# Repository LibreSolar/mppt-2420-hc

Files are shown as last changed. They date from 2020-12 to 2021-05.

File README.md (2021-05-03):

# MPPT charge controller with HS load switch and CAN

 Prototype built and tested, development ongoing (some issues might still be open).

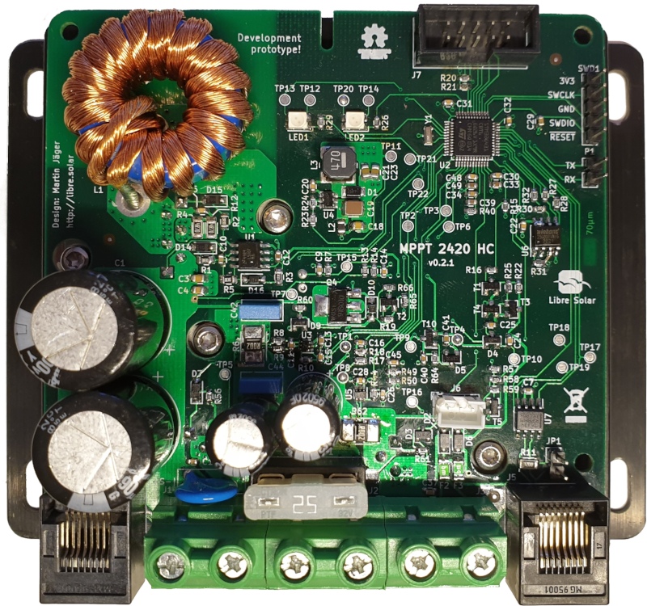
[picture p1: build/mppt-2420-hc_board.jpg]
MPPT 2420 HC


Schematic: [PDF file](build/mppt-2420-hc_schematic.pdf)

Bill of Materials: [CSV file](build/mppt-2420-hc_bom_(hv_supply,can).csv) or [interactive HTML BOM](https://libre.solar/mppt-2420-hc/build/mppt-2420-hc_ibom.html)

Firmware repository: [LibreSolar/charge-controller-firmware](https://github.com/LibreSolar/charge-controller-firmware)

This charge controller design is the replacement for the MPPT 2420 LC. We are also working on an integration of MPPT control algorithms for wind turbines.

## Features

- Solar input terminal
    - Max. 80V (100V MOSFETs used)
    - DC/DC converter inductor current max. 20A
- Battery output terminal
    - 10 V - 32 V (supporting 12 V and 24 V battery systems)
    - Max. current: 20A (limited by inductor current)
- Load terminal: 20A
- New STM32G431 ARM MCU with advanced digital power conversion features
- Expandable via Olimex Universal Extension Connector (UEXT)
- Two bi-color (red/green) LEDs for status indication. Additional user interface can be included in separate PCB in front panel housing and connected via UEXT
- CAN interface via RJ45 connectors

## Mechanical design

- TO-220 MOSFETs can be screwed to large heat sink at the back
- Plastic cover under development

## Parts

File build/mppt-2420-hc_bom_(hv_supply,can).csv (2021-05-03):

Component | References | Value | Footprint | Description | Quantity Per PCB | Manufacturer | PartNumber | Remarks | Config
1 | C11 C15 | 1nF | C_0603_1608 | Unpolarized capacitor | 2 | any
2 | C6 | 2.2nF | C_0603_1608 | Unpolarized capacitor | 1 | any |  | 100V, C0G
3 | C8 C14 C16 C17 C25 C26 C34 C37 C45 | 10nF | C_0603_1608 | Unpolarized capacitor | 9 | any |  | 100V, X7R
4 | C7 C9 C10 C13 C20 C22 C24 C28 C29 C30 C31 C32 C48 | 100nF | C_0603_1608 | Unpolarized capacitor | 13 | any |  |  | +can
5 | C4 | 100nF | C_0805_2012 | Unpolarized capacitor | 1 | any |  | 100V, X7S
6 | C3 C18 | 1µF | C_0805_2012 | Unpolarized capacitor | 2 | any |  | 100V, X7S
7 | C40 | 1µF | C_0603_1608 | Unpolarized capacitor | 1 | Yageo | CC0805KKX7R9BB105 | 50V, X7R
8 | C21 C23 | 10µF | C_0805_2012 | Unpolarized capacitor | 2 | Murata | GRM21BR61E106KA73L | 25V, X5R
9 | C42 C44 | 0.22µF | C_Rect_L7.2mm_W3.5mm_P5.00mm_FKS2_FKP2_MKS2_MKP2 | Unpolarized capacitor | 2 | EPCOS / TDK | B32529C224J | Alternative: Kemet MMK5224K63J01L16.5TA18
10 | C12 C33 C39 C49 | 2.2µF | C_0603_1608 | Unpolarized capacitor | 4 | any |  | 25V, X5R
11 | C19 | 4.7µF | C_1210_3225 | Unpolarized capacitor | 1 | Murata | GRJ32DC72A475KE11L | 100V, X7S
12 | C41 | 4.7µF | C_0603_1608 | Unpolarized capacitor | 1 | Wurth Electronics | 885012107018 | 25V, X5R
13 | C1 C2 | 560µF | CP_Radial_D18.0mm_P7.50mm | Polarized capacitor | 2 | United Chemi-Con | EKZN101ELL561MM25S | 100V, 2.75A, 18x25
14 | C5 C27 | 680µF | CP_Radial_D10.0mm_P5.00mm | Polarized capacitor | 2 | Panasonic | EEU-FR1V681 | 35V, 2.18A, 10x20
15 | D3 D5 | 12V | D_SOT-23_ANK | Diode zener | 2 | ON Semiconductor | SZBZX84C12LT3G | Alternative: Diodes Inc. BZX84C12-7-F
16 | D10 D16 | 1N4148 | D_SOD-123 | Diode | 2 | Diodes Inc. | 1N4148W-7-F
17 | D9 | 47V | D_SOT-23_ANK | Diode zener | 1 | ON Semiconductor | SZBZX84C47LT1G | Alternative: Diodes Inc. BZX84C47-7-F | +hv_supply
18 | D4 | BAS70-04 | SOT-23 | 40V 0.2A Dual Small Signal Schottky Diodes | 1 | ON Semiconductor | BAS70-04LT1G
19 | D2 D6 | NRVTS260ESFT1G | D_SOD-123 | Schottky diode | 2 | On Semiconductor | NRVTS260ESFT1G | Alternative: Nexperia PMEG6020ER,115 | +can
20 | D7 D14 D15 | SS14FL | D_SOD-123 | Diode Schottky | 3 | ON Semiconductor | SS14FL | Alternative: Nexperia PMEG4010EGWX
21 | D1 | SS16FP | D_PowerDI-123 | Diode Schottky | 1 | Diodes Inc. | SS16FP | Alternative: DFLS160-7
22 | F1 | 25A | NULL | Fuse (plug-in) | 1 | Littelfuse | 0287025.PXCN
23 | F2 F3 | 500mA | Fuse_1206_3216Metric | Resettable fuse, polymeric positive temperature coefficient, small symbol | 2 | Bel Fuse | 0ZCJ0050AF2E |  | +can
24 | J4 J5 | 8P8C | RJ45_8P8C | RJ connector, 8P8C (8 positions 8 connected), RJ31/RJ32/RJ33/RJ34/RJ35/RJ41/RJ45/RJ49/RJ61 | 2 | Amphenol FCI | 54602-908LF |  | +can
25 | J6 | JST PH | JST_PH_B3B-PH-K_1x03_P2.00mm_Vertical | Generic connector, single row, 01x03, script generated (kicad-library-utils/schlib/autogen/connector/) | 1 | JST | PH B3B-PH-K 1x3, pitch 2.0mm | LS.pwr
26 | J1 J2 J3 | MKDS 5/ 2-9,5 | Phoenix_Contact_MKDS_5-2-9,5 |  | 3 | Phoenix Contact | 1714971 | Alternative: DECA MB910-952M
27 | J7 | UEXT | Box_Header_2x05x2.54mm_Straight | Olimex UEXT connector (2x5 box header) | 1 | any | Box header 2x5, 2.54mm pitch
28 | JP1 | Jumper_NC_Small | PinHeader_1x02_P2.54mm_Vertical | Jumper normally close | 1 |  |  |  | +can
29 | L2 | 4.7µH | L_0805_2012Metric | Inductor, small symbol | 1 | Murata | LQM21PN4R7NGRD
30 | L3 | 47µH | Bourns_SRN6045TA | Inductor, small symbol | 1 | Tayo Yuden | NR6045T470M | Alternative: Bourns SRR6045TA-470Y
31 | L1 | 53µH | Inductor_Toroid_D32.8mm_4mm2 | Inductor | 1 | Custom (see schematic)
32 | LED1 LED2 | LED_Dual_PLCC4 | LED_Avago_PLCC4_3.2x2.8mm_CW | Dual LED, cathodes on pins 1 and 3 | 2 | Lite-On | LTST-E682KRKGWT | Alternative: Vishay VLMKG3400-GS08
33 | P1 | CONN_01X02 | PinHeader_1x02_P2.54mm_Vertical | Generic connector, single row, 01x02, script generated (kicad-library-utils/schlib/autogen/connector/) | 1 | any | Pin header 1x5, 2.54mm pitch
34 | Q4 | BUK98180-100A | SOT-223-3_TabPin2 | N-MOSFET transistor, gate/drain/source | 1 | Nexperia | BUK98180-100A/CUX | Alternative: Fairchild FQT7N10LTF | +hv_supply
35 | Q1 Q2 Q3 Q7 | IPA045N10N3G | TO-220-3_Horizontal_BottomHeatsink | N-MOSFET transistor, gate/drain/source | 4 | Infineon | IPA045N10N3G | Alternative: IPP045N10N3G
36 | R6 R62 | 2m | R_Bourns_CRE2512 | Resistor | 2 | Bourns | CRE2512-FZ-R002E-3
37 | R1 R2 R3 R5 | 3R3 | R_0805_2012 | Resistor | 4 | Yageo | RC0805FR-073R3L
38 | R4 R12 | 4R7 | R_1206_3216 | Resistor | 2 | Yageo | RC1206FR-074R7L
39 | R8 R9 | 10R | R_0603_1608 | Resistor | 2 | any |  | 1%
40 | R27 R28 R32 R40 | 47R | R_0603_1608 | Resistor | 4 | any |  | 1%
41 | R11 | 120R | R_1206_3216 | Resistor | 1 | any |  | 1%
42 | R10 R25 R26 R29 R66 | 1k | R_0603_1608 | Resistor | 5 | any |  | 1% | +hv_supply
43 | R14 R20 R21 R31 R44 R57 | 2.2k | R_0603_1608 | Resistor | 6 | any |  | 1%
44 | R18 | 5.6k | R_0603_1608 | Resistor | 1 | any |  | 1%
45 | R50 | 8.2k | C_0603_1608 | Resistor | 1 | any |  | 1%
46 | R7 R16 R19 R24 R49 R59 R64 | 10k | R_0603_1608 | Resistor | 7 | any |  | 1% | +hv_supply
47 | R23 | 33k | R_0603_1608 | Resistor | 1 | any |  | 1%
48 | R13 R17 R22 R30 R58 R60 R65 | 100k | R_0603_1608 | Resistor | 7 | any |  | 1% | +hv_supply
49 | R15 R56 R61 | 1M | R_0603_1608 | Resistor | 3 | any |  | 1%
50 | RT1 | 10k | C_Disc_D3.8mm_W2.6mm_P2.50mm | Temperature dependent resistor, negative temperature coefficient | 1 | TDK | NTCG163JF103FT1S
51 | RV2 | 82V | RV_Disc_D12mm_W4.3mm_P7.5mm | Voltage dependent resistor | 1 | Bourns | MOV-10D820K
52 | SWD1 | ST_Nucleo_SWD | PinHeader_1x05_P2.54mm_Vertical | STM32 Nucleo Board SWD connector (5 pins w/o SWO) | 1 | any | Pin header 1x5, 2.54mm pitch
53 | T1 T2 T3 T5 T10 | BC846B | SOT-23 | 0.1A Ic, 65V Vce, NPN Transistor, SOT-23 | 5 | ON Semiconductor | BC846BLT1G |  | +hv_supply
54 | T4 | BC856B | SOT-23 | 0.1A Ic, 65V Vce, PNP Transistor, SOT-23 | 1 | ON Semiconductor | BC856BLT1G
55 | U3 U5 | INA186 | SOT-363_SC-70-6 | Bidirectional, Low- and High-Side Voltage Output, Current-Sense Amplifier, SC-70 | 2 | Texas Instruments | INA186A1IDCKR
56 | U1 | LM5107 | SOIC-8_3.9x4.9mm_Pitch1.27mm |  | 1 | Texas Instruments | LM5107MAX/NOPB
57 | U4 | LMR16006X | SOT-23-6 | SIMPLE SWITCHER® 4V to 60V, 600mA Step-Down Regulator with Low Iq | 1 | Texas Instruments | LMR16006XDDCR
58 | U2 | STM32G431CBTx | LQFP-48_7x7mm_P0.5mm | ARM Cortex-M4 MCU, 128KB flash, 22KB RAM, 170MHz, 1.71-3.6V, 66 GPIO, LQFP-48 | 1 | ST Microelectronics | STM32G431CBT6
59 | U7 | TCAN334 | SOIC-8_3.9x4.9mm_Pitch1.27mm | High-Speed CAN Transceiver, 1Mbps, 3.3V supply, low power standby mode, shutdown mode, SOT-23-8/SOIC-8 | 1 | Texas Instruments | TCAN334DR |  | +can
60 | U6 | W25Q80DVS | SOIC-8_3.9x4.9mm_Pitch1.27mm | 128Mb Serial Flash Memory, Standard/Dual/Quad SPI, SOIC-8 | 1 | Winbond | W25Q80DVSNIG
61 | XF1 | Fuse_Holder | Keystone-Fuse-3557-2 | Fuse holder | 1 | Keystone | 3557-2
62 | Y1 | 8MHz | Resonator_Murata_CSTNE | Two pin crystal | 1 | Murata | CSTNE8M00GH5C000R0 | 0.07% | +can

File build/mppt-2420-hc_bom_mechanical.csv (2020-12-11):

Component | Description | Material | Quantity Per PCB | Manufacturer | PartNumber | Remarks
1 | Screws for MOSFETs, M3x10 | A2 stainless steel | 4 | any
2 | Self-retaining spacer, D2.5mm, H4.5mm | Nylon 66, natural | 2 | Würth Elektronik | 702916000
3 | Thermal pad |  | 5 | any
4 | Glue for inductor |  | 1 | any
5 | Heat sink | Aluminum | 1 | Libre Solar | 10001

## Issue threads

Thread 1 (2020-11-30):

Some questions

moritz31, 2020-11-30:
I have a few questions:

Could this Board be soldered by hand or do i need to Order it.

What is the minimal Input for this Board ? I currently have a 3W Solar Panel, will That work ?

martinjaeger, 2020-11-30:
It can still be hand-soldered if you have some soldering experience with fine pin-pitch parts. I usually solder the first prototypes by hand aswell.

3W is most probably too small and the control algorithms would most probably not work properly anymore. This board is more suited for something up to 300W (at a 12V battery).

moritz31, 2020-12-03:
Thank you for the answer. I have done different electrical stuff already and soldered some smaller chips so it is Worth a try.

For the power side: i am currently building a Battery pack at 24V and the Solar side is not determined, is there something which works with a 20-50W Solar Panel ?

theonaldovncts, 2023-07-16:
Hey I want to ask, If I want to adopt the charge controller for a wind turbine, which terminal do I need to connect to dump load?

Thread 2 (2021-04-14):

Inductor saturation for 24V batteries

martinjaeger, 2021-04-14:
The inductor layout turned out to be too optimistic for full power (20A) in 24V systems. As the ripple current increases with the output voltage, the inductor is driven into saturation and the core gets too warm (>80°C).

We are currently doing further testing with a larger inductor wound around two stacked cores such that it will still fit to the PCB as it is now. Updates after testing will be posted here.

intrinsicaly, 2023-11-19:
Did you mange to progress any further with this one?

martinjaeger, 2023-11-20:
Yes, kind of. It works very well with larger inductor, but the board design would have to be updated to fit the inductor.

intrinsicaly, 2023-11-26:
Is that something you are considering by any chance?

martinjaeger, 2023-11-27:
Not at the moment, unfortunately. Have to focus on some paid-for projects first.

intrinsicaly, 2023-11-30:
I appreciate that. Thanks for your works thus far.

intrinsicaly, 2024-03-08:
Hi Martin,
I note on your schematic pdf that you have 2 stacked ms-130060-2 cores. Is that in response to this issue of saturation or is this the original design?

martinjaeger, 2024-03-08:
Two stacked cores is one possible solution. Another solution would be a larger core in general.
The original design had only one core.

intrinsicaly, 2024-03-11:
Thanks for that.
I appreciate your time while you are busy with paid work.
Would you be able to help this novice with some info from the design.
Looking at the design schematic I can see that you are targeting 53uH for the inductor, 21 turns 27AWG 40 strand copper wire but I am unsure of the info below;
VLon (V) and VLoff (V) and f(Hz)

glenndk, 2025-06-18:
> The inductor layout turned out to be too optimistic for full power (20A) in 24V systems. As the ripple current increases with the output voltage, the inductor is driven into saturation and the core gets too warm (>80°C).
>
> We are currently doing further testing with a larger inductor wound around two stacked cores such that it will still fit to the PCB as it is now. Updates after testing will be posted here.

Please look at:
https://github.com/LibreSolar/mppt-2420-hc/issues/10

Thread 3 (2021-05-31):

160V from PV possible or more?

dPeS, 2021-05-31:
first of all - great project!

context: I'm mostly IT guy - familiar with coding but also electronics is my hobby. I have 4 x 450W PV (41V shorted) in series that I use for heating water via MPPT controler (commercial). Durring sunny day at 13:00-14:00 water is already at 65C and want to redirect that 160V (4x40) into 4x12V acid accu.

Is it possible to change that mosfet into more powerfull and drive 160V or more?

martinjaeger, 2021-05-31:
Unfortunately, that won't be easily possible. It's not only the MOSFET, but also several other components that would need to be changed, e.g. the capacitors and the MOSFET driver. It's basically a new PCB design...

dPeS, 2021-05-31:
@martinjaeger but it is possible to make 12v output from 160V?

if you guide me I could replace driver + buy caps for higher volts - you will have free stress testing :]

martinjaeger, 2021-05-31:
It is possible in general, but the input voltage steps for the MPPT algorithm become very coarse because of the high ratio between input and output voltage. This microcontroller runs at 150 MHz, which is already quite good for the PWM signal resolution.

I don't think there is a pin-compatible driver for higher voltage (with similar drive current capabilities). If you find one, let me know...

dPeS, 2021-06-21:
@martinjaeger IPP110N20NA from infineon will do the job?

X-Ryl669, 2021-11-04:
You can have 2 board and plug 2 PV panels in series on one board and the other 2 on another board. You'll then charge 2 12V batteries independently. Beware not to connect the batteries on the same load circuit (since it would share the different voltage ground).

DodoidOfficial, 2025-04-21:
> I don't think there is a pin-compatible driver for higher voltage (with similar drive current capabilities). If you find one, let me know...

Apologies for the reply to the ancient issue. I am also interested in using the MPPT-2040-HC with higher-voltage panels. The panels I am interested in are ~150Voc each, so unfortunately shortening the string is not an option (and most off-the-shelf MPPTs won't work!). I've already made a few PCB tweaks to accommodate larger capacitors on DCDC_HV+ and increase a few clearances for a 200V rating.

Suitable drop-in FETs and capacitors seem to be available. For the gate driver, the [IRS21867STRPBF](https://www.mouser.ca/datasheet/2/196/Infineon_IRS21867S_DataSheet_v01_00_EN-3363603.pdf) looks like a drop-in replacement. The only downside I can see is longer (up to 250ns) propagation times (I couldn't totally figure out the range of PWM frequencies this uses - are these too long?). Other than that it has 4A of drive current, 3.3V-compatible inputs, it looks to be the same pinout, should run off the 12V supply, and it's rated up to 600V.

Do you see any reason this wouldn't work?

echedey-ls, 2025-05-01:
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

@DodoidOfficial I'm interested in this conversation. From [the schematics](https://github.com/LibreSolar/mppt-2420-hc/blob/main/build/mppt-2420-hc_schematic.pdf), I think the main problem could be with the 12V supply circuit, the voltage follower in page 3. It will need to provide more current due to increased gate capacitance. I don't know how much nor if it can handle it well. What MOSFETs were you talking about?

DodoidOfficial, 2025-05-03:
@echedey-ls I was looking at the MASPOWER [MS130N20JDT0](https://www.lcsc.com/product-detail/MOSFETs_MASPOWER-MS130N20JDT0_C37635851.html). You can get similar, more-name-brand parts from Mouser, etc but it looked like you'd be spending $40+ on FETs alone if you did.

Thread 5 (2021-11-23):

Parrallel diode for efficiency improvement ?

Light411, 2021-11-23:
Hello everyone,

I was looking at the MPPT-2420 layout today, and I was thinking maybe it would be useful to add a small shottky diode between the switching node and ground.

From the transistor datasheet we get that the body diode recovery charge is about 135nC (this is not helping much because it heavily depends on the A/us slope rate), but from that info we can estimate the added switching loss that would be about

Qrr*fs*VIn = 0.5W approx. loss for a diF/dt of 100A/µs

Do you know if this diF/dt is somewhere near the actual switching characteristics ?
Maybe it's worth added a 100V diode ?

Here is an application note from TI I found quite interesting that covers the topic quite well IMO.
https://training.ti.com/sites/default/files/docs/not-all-regulators-are-created-equal-synchronous-v-non-synchronous-presentation.pdf

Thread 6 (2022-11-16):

Any Companies adopted this design?

Aliqyaan, 2022-11-16:
Hello,
First of all I would like to congratulate y'all for this development. It looks very compact and hopefully works well too.

I wanted to know if there is any company who has adopted your design and made a product out of it. As i wanted to buy one on the shelf product.

Any leads would be appreciated :)

martinjaeger, 2022-11-16:
Hey. Thanks for the comment.

I'm not aware of any company which adopted this design. I released the design just when no STM32 microcontrollers were available anymore due to global chip shortage. So I doubt you will find anyone who produced the boards in larger quantities to buy off the shelf.

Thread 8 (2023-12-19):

MPPT's in parallel

intrinsicaly, 2023-12-19:
Hi Martin,
I hope all is well.
Thanks for all your work on this project to date.
Would there be any issues if I put these mppt's in parallel?
I am looking at setting up a 24v lithium battery at either 280A or 560A/hr so I am want to put up to 2kw of panels on the roof.
Based on the specs of the mppt and the solar panels that I have, I can only have two panels in parallel/mppt so I would need up to 5 of these mppt's. Is this feasible?
The panel spec's are as follows;
Voc - 45.84V
Isc - 5.70A
Vmpp - 36.97V
Impp - 5.41A
This setup will be around 17A so will be close to the 20A issue that you have described in another issue. Do you forsee this as an issue as the mppt will spend a lot of the day at this value?

Thanks again for all your work.

Cheers

martinjaeger, 2023-12-20:
Hi @intrinsicaly,

Yes, in general it is feasible to put multiple MPPTs in parallel. However, due to voltage measurement tolerances, their charging algorithms could behave slightly different, which may lead to issues because they switch from one charging mode to another at different times. This would be more severe for Lead-Acid batteries than for Li-ion batteries, though.

We did an experiment a while ago to control multiple MPPTs in parallel using CAN for exchanging control parameters. The important CAN part can be seen [here](https://github.com/LibreSolar/charge-controller-firmware/blob/e175ad0fdb1efc7ca0c7e75a947c1cfec49023cd/app/src/ext/can.cpp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). The basic idea is that the node with the lowest node address automatically becomes the master and the others take the master's MPPT algorithm current as their target current. This worked well in the lab, but we haven't been able to test it any further in the field.

Long story short: I would just try it out, it should even work without communication for your setup with a Li-ion battery.

Regarding the current close to 20A: This could indeed be an issue. You could limit the current to 15A by software for the 24V battery. Just adjust the value in the [devicetree file](https://github.com/LibreSolar/charge-controller-firmware/blob/e175ad0fdb1efc7ca0c7e75a947c1cfec49023cd/boards/arm/mppt_2420_hc/mppt_2420_hc.dts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).

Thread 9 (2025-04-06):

why are MPPT chargers?

jlmxyz, 2025-04-06:
Hi,
the original topic is described on https://community.victronenergy.com/t/multiple-charger-one-slave/27969
after posting, I asked myself if there was some open source hardware projects and gladly found LibreSolar!

so my question is related to https://github.com/LibreSolar/mppt-2420-hc/issues/8
but a bit more general : in my case I will have 2 MPPT and also a DC/DC from the alternator or 2MPPT and a AC/DC
all have battery charge algorithms.....

1) I don't get why duplicating the function multiple time (in case of one battery, there are 4 charging functions for one battery)
2) since all charger have charge algorithm, they need to synchronise....

so my question is why aren't they only "power optimized DC/DC" that only provide a tension (like the grid provide 220/110V) on which the charger are plugged? (like my laptop charger, my phone charger...)

and why not create a BMS that is really a BMS, not just a battery protection.... I would LOVE to have a board only to manage the charge of the battery and back (have a input connector for the power from the providers, and an output connector to deliver me stabilized onboard voltage on which I can plug my DC/DC converters (USB chargers....) so that all batteries are independent, can be different chemicals, different power, charge... )

best regards

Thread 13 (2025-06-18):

mppt-2420-hc big matrix coupled magnetic structure for SMPS (suggestion)

glenndk, 2025-06-18:
Hi LibreSolar

Thanks for sharing your free source code and open hardware.

I have looked at the schematics of mppt-2420-hc.

If you want to desigm a big SMPS then look here - at the multi-phase Cuk converter with the matrix coupled magnetic structure:

Matrix Coupled All-in-One Magnetics for PWM Power Conversion:
https://www.princeton.edu/~minjie/files/ping-matrix-2022.pdf
backup:
https://web.archive.org/web/20240107230553/https://www.princeton.edu/~minjie/files/ping-matrix-2022.pdf
Quote: "...
The matrix coupled SEPIC prototype can support load current up to 185 A at 5 V-to-1 V voltage conversion3 with a maximum power density over 470 W/in . Compared to commercial discrete inductors, the matrix coupled inductor has a 5.6 times smaller size and 8.5 times faster transient speed with similar current ripple and current rating.
...
For the multi-winding transformer, cross-sectional area of the magnetic core doesn’t scale up with the winding count, but depends on the maximum volt-second-per-turn of all the windings [9]–[14]. The total VA power rating scales faster than the transformer volume [2]. Thus, integrating many transformers into a single multi-winding transformer with the same total power rating can reduce the overall transformer size.
...
To validate the matrix coupled magnetic structure and theoretical analysis, a four-phase matrix coupled synchronous SEPIC converter with planar PCB integrated magnetics is designed and tested. The prototype measures 0.392 in3 in vol- ume and is capable of flexibly delivering power from 1∼5 V input to 1∼5 V output. At 5 V-to-1 V voltage conversion, the prototype can support load current up to 185 A with power3 density over 470 W/in . Compared to discrete commercial inductors of similar current ratings and ripples, the matrix coupled inductor reduces the magnetic component size by over 5.6 times and increases the transient speed by over 8.5 times.
...
The analysis above reveals that the benefits of parallel coupling fundamentally come from multiphase interleaving. Similar conclusion is drawn from a different perspective in [8].
...
Multiphase Ćuk
..."

-

Combine thes with input and output AC-filtering. Filtering is necessary for CE-approval.

I would suggest that both input and output Ćuk converter inductors must be exchanged for smoothing transformers. Both smoothing transformers must be placed very close to the switching MOSFETs/diode. Result: Nearly zero-ripple input and output (if Continuous Conduction Mode is used) - I assume:

1999, A ‘Zero’ Ripple Technique Applicable To Any DC Converter:
https://static.elitesecurity.org/uploads/3/6/3617667/azrtatad.pdf
backup:
https://web.archive.org/web/20250618153700/https://static.elitesecurity.org/uploads/3/6/3617667/azrtatad.pdf

AN3180 Application note.
A 200 W ripple-free input current PFC pre-regulator with the L6563S:
https://www.st.com/resource/en/application_note/an3180-a-200-w-ripplefree-input-current-pfc-preregulator-with-the-l6563s-stmicroelectronics.pdf
https://web.archive.org/web/20220222031842/https://www.st.com/resource/en/application_note/an3180-a-200-w-ripplefree-input-current-pfc-preregulator-with-the-l6563s-s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

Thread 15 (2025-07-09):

pcb file fail to open on kicad 9.0.2

jlmxyz, 2025-07-09:
tried to open the pcb file with kicad 9.0.2
it show the following error :
Expecting 'text value' in './mppt-2420-hc/kicad/mppt-2420-hc.kicad_pcb', line 8481, offset 12.

thanks and regards

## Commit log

2020-11-18 Small updates in layout and documentation (v0.1.1)
    [can.sch, dcdc.sch, load-switch.sch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]
2020-12-11 Update to v0.2 with improvements after testing
    [can.sch, dcdc.sch, load-switch.sch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]
2021-01-08 Minor updates for v0.2.1
    Adjustments in silk screen and second bulk output cap.
    [can.sch, dcdc.sch, load-switch.sch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]
2021-03-17 v0.2.2: Bugfixes for SPI flash and sense resistor
    - Correct value of load current sense resistor to 2 mOhm
    - Connect SPI flash WP and HOLD pins to 3V3
    [can.sch, dcdc.sch, load-switch.sch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]
2021-05-03 License update and larger inductor (v0.2.3)
    - Change license to CERN-OHL-W-2.0, which is more suitable for hardware
    - Use larger nominal 53 uH inductor to support 20A also for 24V systems
    - Increase input capacitor height to 25 mm (inductor needs more space anyway)
    - Update schematic template and text fields
    - Use photo instead of rendered image
    [can.sch, dcdc.sch, load-switch.sch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]
